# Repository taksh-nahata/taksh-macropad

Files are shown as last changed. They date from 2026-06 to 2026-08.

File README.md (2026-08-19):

# Nexus-4 (my first piece of hardware)

Okay, okay, okay. Let me introduce you to Nexus-4, a custom 4-key macropad. It features an inverted-T arrow key layout, a 128x32 OLED display, and a 3D-printed sandwich-mount case. So I run the the software of this on a Seeed Studio XIAO RP2040 that runs my custom QMK firmware. I've even made some simple ASCII art animations(currently very simple tho)!

---

## Completed Build & Demo

<p align="center">
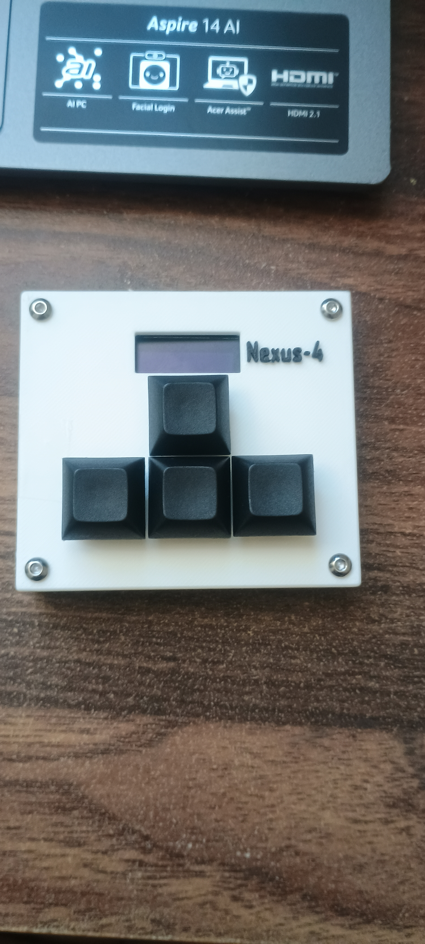
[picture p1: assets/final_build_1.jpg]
Finished Nexus-4 Top View
  
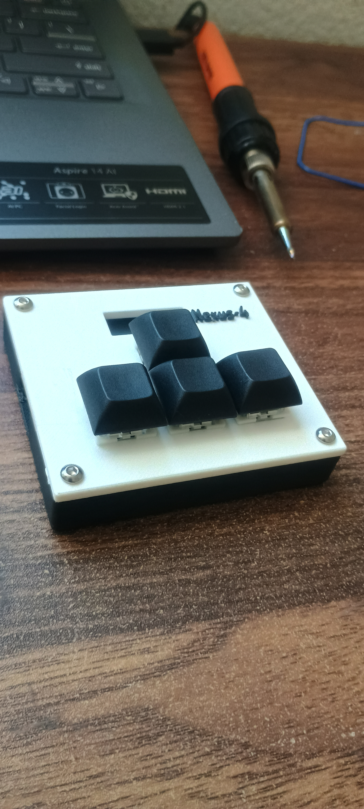
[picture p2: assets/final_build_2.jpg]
Finished Nexus-4 Angle View
  
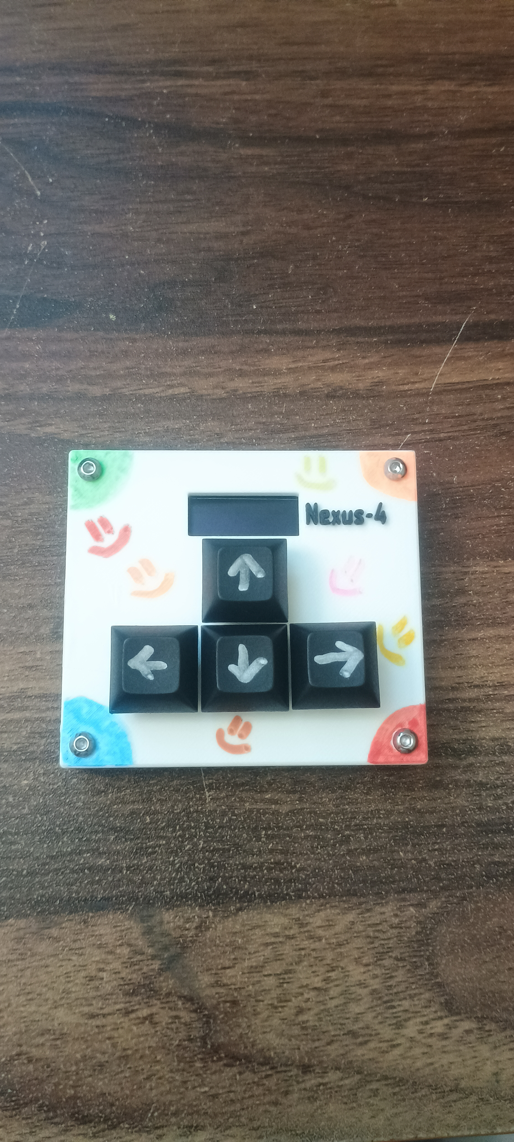
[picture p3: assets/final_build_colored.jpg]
Built and colored Nexus-4 Top View
  
</p>

### Video Demonstration
[Watch the Nexus-4 in action](https://drive.google.com/file/d/1Elsz5yWcckBbZZuh22iVLzsOhnGGIkVX/view?usp=sharing)

---

## Some Features
* **Custom 3D-Printed Enclosure:** So basically, I made a two-piece sandwich-mount case (Top Plate + Bottom Case) which are connected together using screws at the corner.
* **Interactive OLED Animation:** I've got a 0.91" 128x32 I2C OLED display at the top middle of the macropad, which shows ASCII animations that I made, and they react to your keystrokes.

---

## Hardware & CAD Design

The cadded box I made for the macropad is a sandwich-mount structure, and I made it on Fusion 360. The PCB rests inside this enclosure, and it is topped by the Top Plate, which is secured using screws at the four corners. I've also made a side cutout in the Bottom Case, to give access to the RP2040's USB-C connector.

<p align="center">
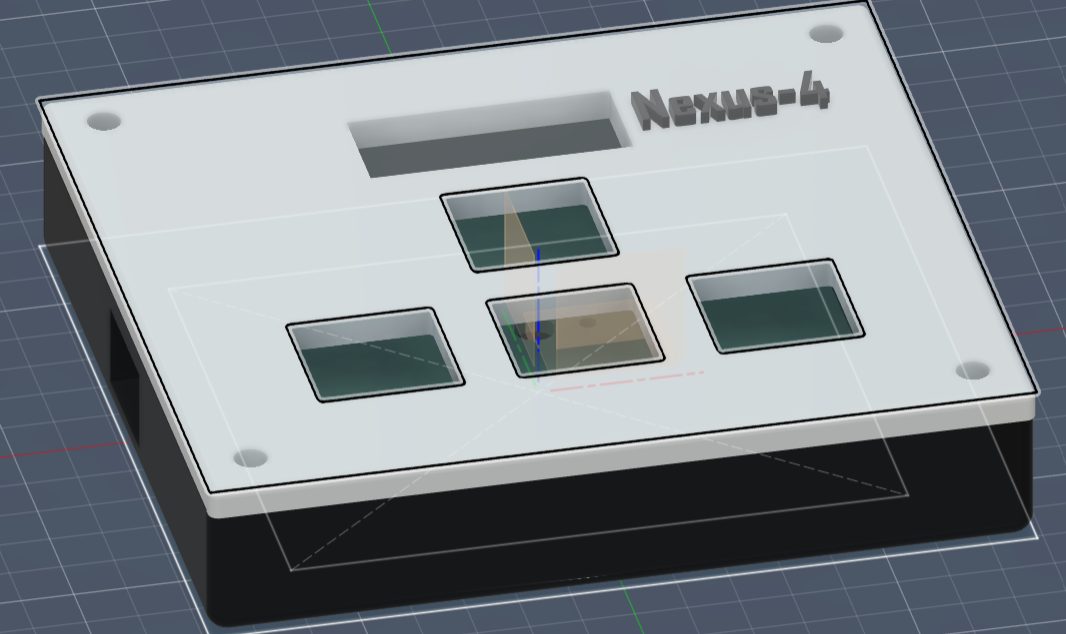
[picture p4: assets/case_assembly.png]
Case Assembly
  
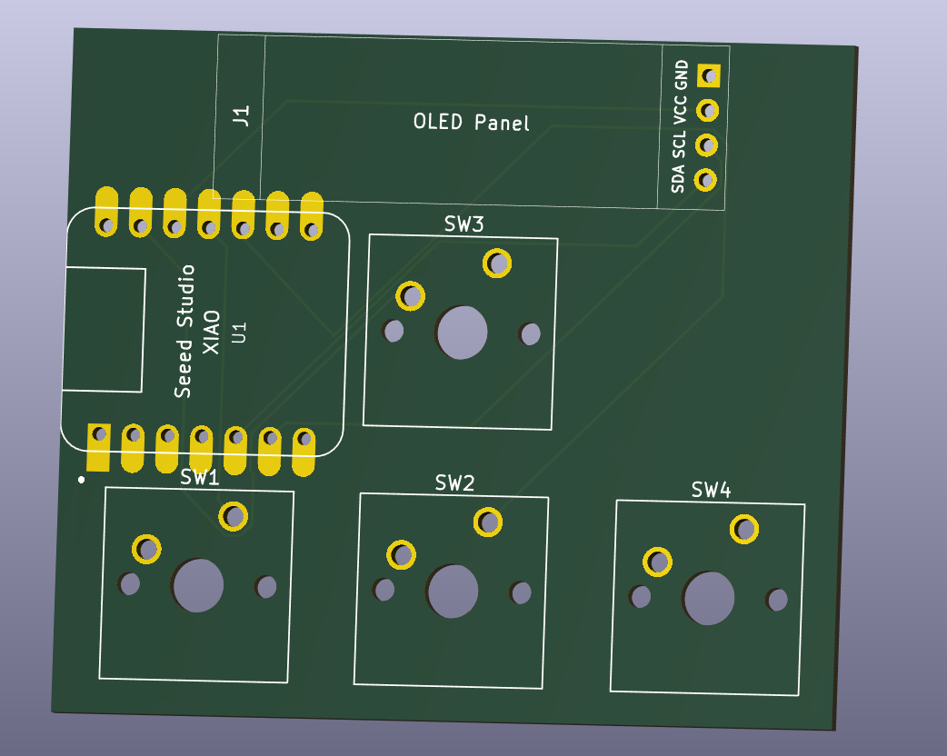
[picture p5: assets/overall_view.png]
Overall View
  
</p>

---

## PCB & Schematic

I made the PCB in KiCad completely. I used direct-pin connections to simplify the overall layout and also reduce the number of components I need.

* **Microcontroller:** Seeed Studio XIAO RP2040
* **Display Interface:** I2C (SDA on `GP6`, SCL on `GP7`)
* **Switch Routing:**
  * **Up Switch (SW1):** `GP2` (Pin D8)
  * **Left Switch (SW2):** `GP3` (Pin D10)
  * **Down Switch (SW3):** `GP4` (Pin D9)
  * **Right Switch (SW4):** `GP1` (Pin D7)

<p align="center">
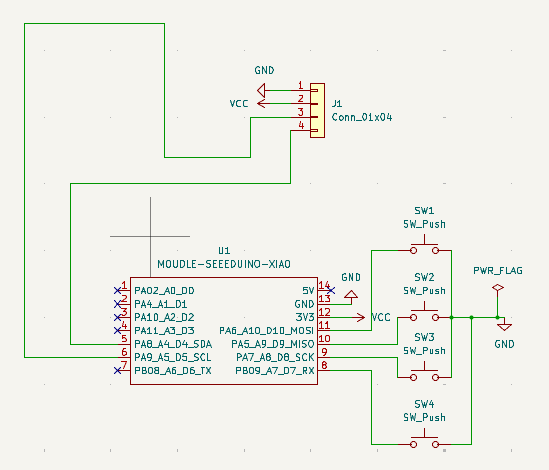
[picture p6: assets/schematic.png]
Schematic
  
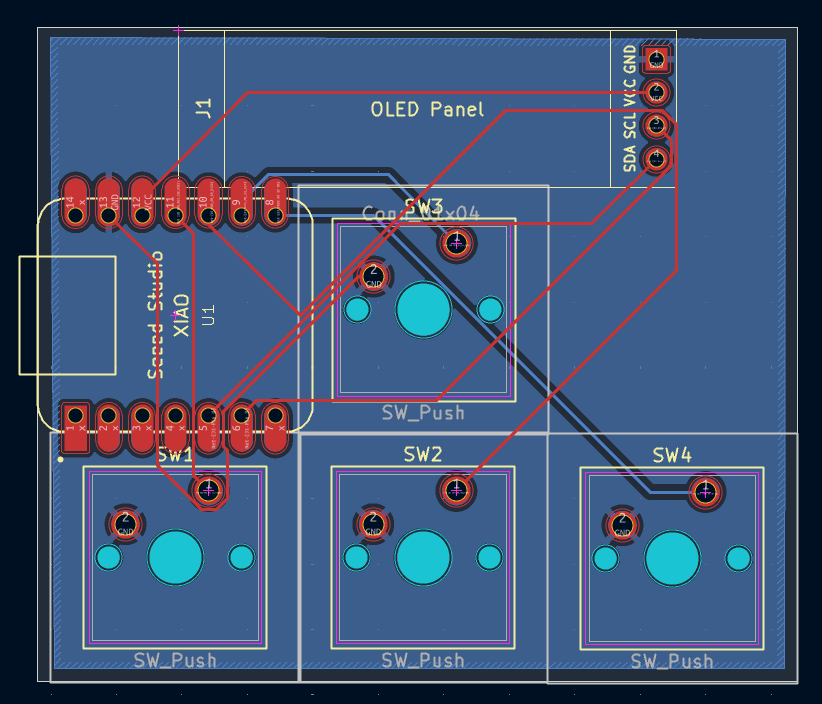
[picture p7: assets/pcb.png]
PCB Layout
  
</p>

---

## Firmware & OLED Logic

The firmware is compiled with QMK for the RP2040 (`promicro_rp2040` target).

Layout:
* `KC_UP` (Up Arrow)
* `KC_LEFT` (Left Arrow)
* `KC_DOWN` (Down Arrow)
* `KC_RIGHT` (Right Arrow)

* **Keymaps:** This is pretty standard and straight forward. It's just mapped to standard navigation keys (`KC_UP`, `KC_LEFT`, `KC_DOWN`, `KC_RIGHT`).
* **OLED Engine:** The OLED screen shows an inverted (because the OLED is positioned the wrong way on the PCB), and centered ASCII text and animation. When there are no keys being pressed, there is a simple breathing sleep animation (`zZz`) and this cycles continuously. Pressing any key triggers `process_record_user()` to update the active expression in the direction of input (`owo`, `>_<`, `o_o`, `-w-`).

---

## Bill of Materials (BOM)

This does not include all tools I used to build this. Only the components which are directly on the macropad. To view a full list of materials, you can view the BOM file I've attached to this repo.

| Category | Component | Quantity |
| :--- | :--- | :--- |
| **Electronics** | Seeed Studio XIAO RP2040 | 1 |
| **Electronics** | 0.91" 128x32 I2C OLED Display | 1 |
| **Electronics** | Cherry MX-Compatible Switches | 4 |
| **Electronics** | Custom 2-Layer PCB | 1 |
| **Hardware** | 3D-Printed Top Plate | 1 |
| **Hardware** | 3D-Printed Bottom Case | 1 |
| **Hardware** | M4 (or M3) Screws & Nuts | 4 |
| **Keycaps** | 1u Keycaps | 4 |

---

## How can you make this?

1. **Surface-Mount the microchip:** Start by soldering the RP2040 chip directly, flat to the PCB pads, using its castellated edges. This is to ensure that the chip is not raised any more than necessary to give enough spaces for the pins of the switches.
2. **Mount the OLED:** Remove the plastic collar from the 4 pin header and then solder the bare pins between the PCB and the OLED. You will need to solder both sides, on the back side of the PCB and on top of the OLED, to ensure the connection is secure.
3. **Mount the Switches:** Fit the switches perfectly into the holes from the top of the Top Plate (you will hear a click), and then you can align the PCB with the pins of the switches. Once perfectly aligned and all pins are somewhat through the holes of the PCB, you can solder them all to the PCB. Feed 2-3 mm of solder for this.
4. **Enclosure Assembly:** You're basically done! Just drop the PCB assembly into the bottom case and then secure the sandwich using four corner bolts and nuts.
5. **Flash Firmware:**
   * Enter bootloader mode by holding the **Boot** key or grounding `GP26` (`D0`) on startup to mount the `RPI-RP2` drive.
   * Compile and copy the `.uf2` file:
     ```bash
     qmk compile -kb taksh_macropad -km default
     ```
   * Drag and drop `Nexus-4_default` into `RPI-RP2`.

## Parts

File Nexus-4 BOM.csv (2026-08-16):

Item | Price | Link
XIAO RP2040 Module | $11.50 | https://www.aliexpress.us/item/3256806765635713.html?mp=1
1X15Pin (10PCS) Male Header Pins | $2.05 | https://www.aliexpress.us/item/3256805730789728.html?mp=1
OLED display module white | $2.20 | https://www.aliexpress.us/item/3256808453793642.html?mp=1
Outemu Switches Mechanical Keyboard | $2.31 | https://www.aliexpress.us/item/3256804099108371.html?mp=1
Electric Soldering Iron Kit Set | $11.20 | https://www.aliexpress.us/item/3256802914298493.html?mp=1
M3 Screws | $2.97 | https://www.aliexpress.us/item/3256805785441514.html?mp=1
DSA Black Keycaps | $4.42 | https://www.aliexpress.us/item/3256808457115497.html?mp=1
Solder Wire | $7.39 | https://www.amazon.com/TOWOT-Purity-Electrical-Soldering-Content/dp/B09KM2LW4G?channelId=500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

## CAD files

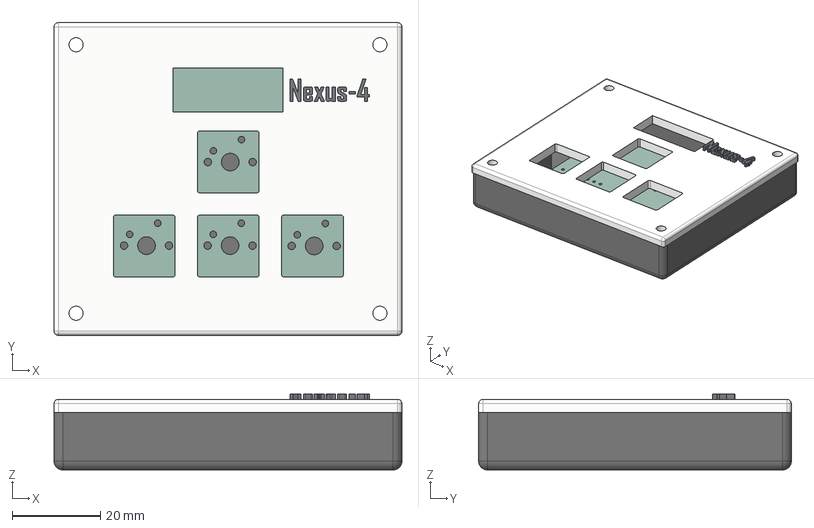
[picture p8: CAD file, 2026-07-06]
CAD/Nexus-4.step
78.8 x 70.8 x 17.2 mm
R_0805_2012Metric_1 x 2
Nexus-4_PCB

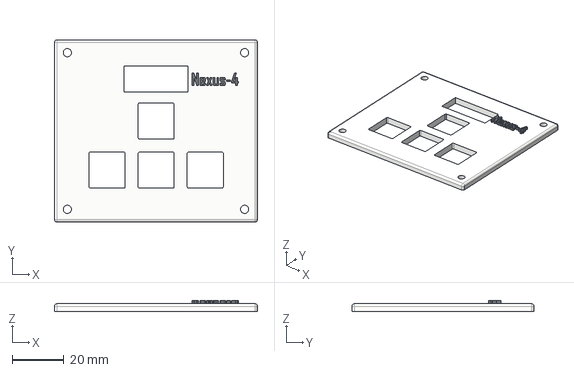
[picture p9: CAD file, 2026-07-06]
production/Top Plate.step
78.8 x 70.8 x 4.20 mm

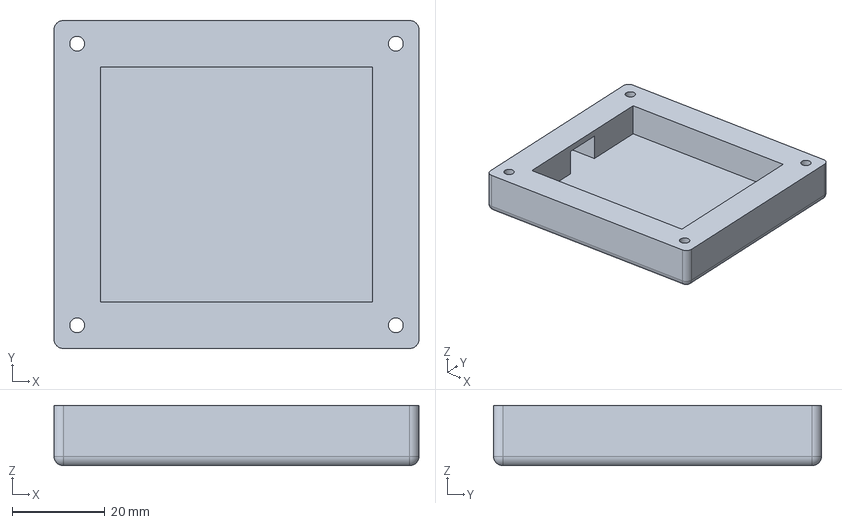
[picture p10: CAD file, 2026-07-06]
production/Bottom Case.step
78.8 x 70.8 x 13.0 mm

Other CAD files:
CAD/Nexus-4 CAD.f3z
production/Bottom Case.stl
production/Top Plate.stl

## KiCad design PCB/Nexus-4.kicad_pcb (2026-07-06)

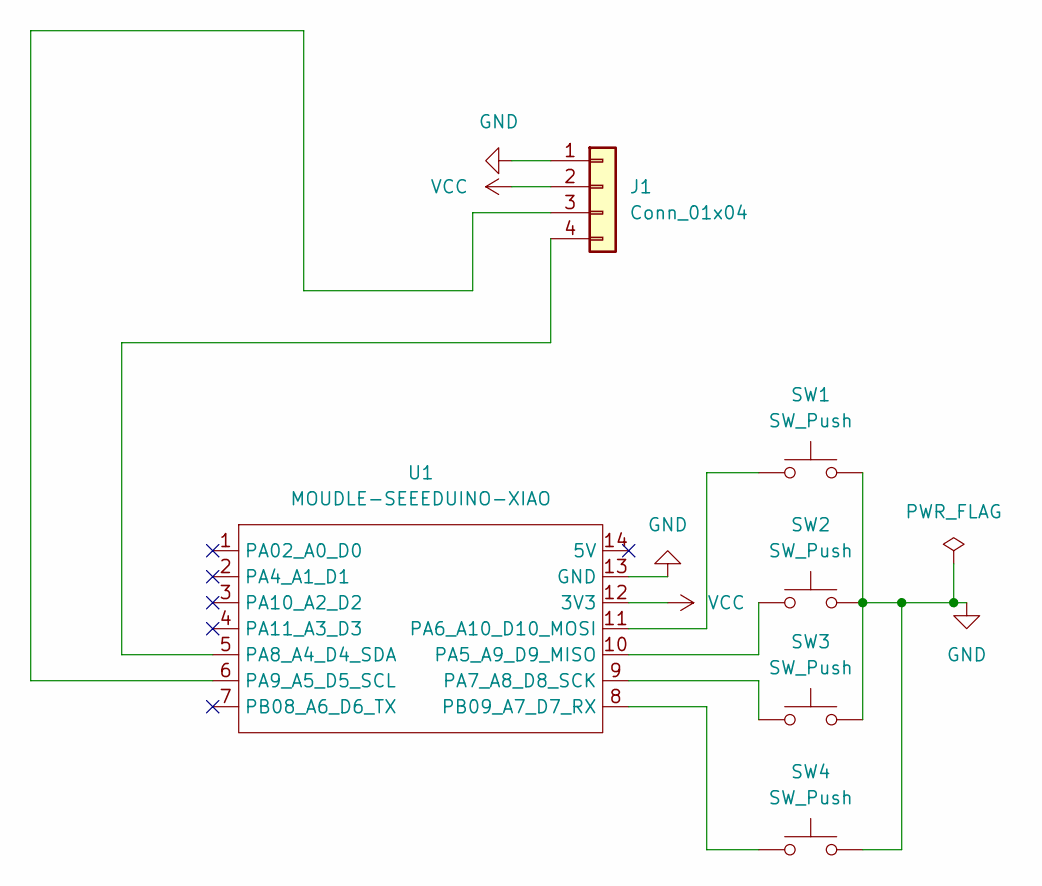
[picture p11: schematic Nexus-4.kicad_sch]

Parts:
J1: Conn_01x04; SSD1306-0.91-OLED-4pin-128x32
SW1, SW2, SW3, SW4: SW_Push; SW_Cherry_MX_1.00u_PCB
U1: MOUDLE-SEEEDUINO-XIAO; XIAO-Generic-Hybrid-14P-2.54-21X17.8MM

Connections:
GND: J1.1, SW1.2, SW2.2, SW3.2, SW4.2, U1.13 (GND)
unnamed: J1.3, U1.6 (PA9_A5_D5_SCL)
unnamed: J1.4, U1.5 (PA8_A4_D4_SDA)
unnamed: SW2.1, U1.10 (PA5_A9_D9_MISO)
unnamed: SW1.1, U1.11 (PA6_A10_D10_MOSI)
unnamed: SW3.1, U1.9 (PA7_A8_D8_SCK)
unnamed: SW4.1, U1.8 (PB09_A7_D7_RX)
VCC: J1.2, U1.12 (3V3)

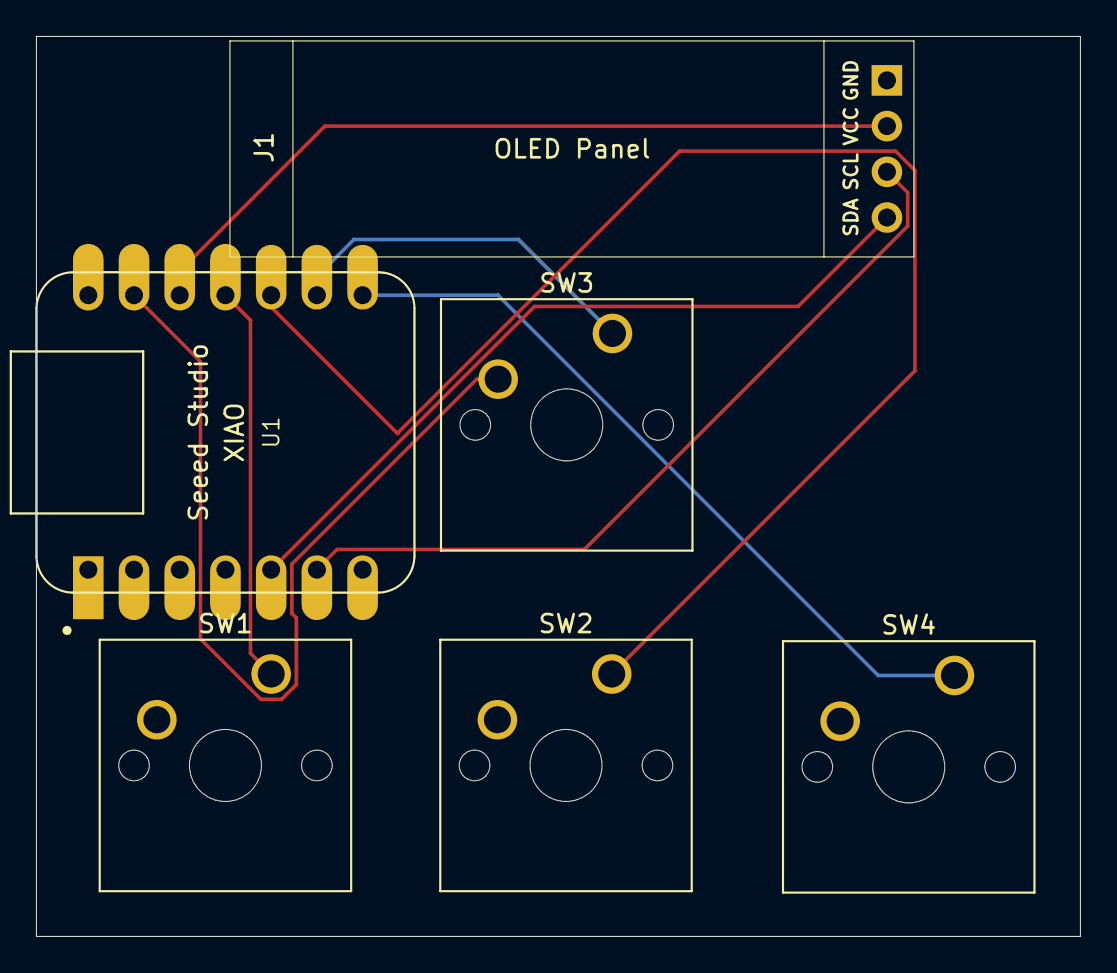
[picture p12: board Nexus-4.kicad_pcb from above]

Board: 2 copper layers, 58.0 x 50.0 mm, 6 parts (0 on the bottom side), 8 nets.

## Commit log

2026-06-01 Updated Entire Macropad to include all production details and original parts
    [Bottom Case.step, Macropad_Master.step, Top Plate.step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]
2026-06-01 add kicad prl
2026-06-09 fixed changes asked
    [Bottom Case.stl, Macropad offical - Taksh Nahata.f3z, Top Plate.stl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]
2026-06-09 adjusted some placements
    [Bottom Case.stl, Macropad offical - Taksh Nahata.f3z, my_macropad.kicad_pcb]
2026-06-11 fixed some changes and made it look more asthetic overall
    [Bottom Case.stl, Macropad offical - Taksh Nahata.f3z, Top Plate.stl]
2026-06-15 added BOM and updated README
    [Taksh Macropad BOM.csv]
2026-07-06 Refactor code structure for improved readability and maintainability
    [Bottom Case.step, Bottom Case.stl, Macropad offical - Taksh Nahata.f3z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]
2026-08-16 fixed readme, added finished build pics, fixed BOM, and pushed updated keyboard.json and keymap.c
    [Nexus-4 BOM.csv]
